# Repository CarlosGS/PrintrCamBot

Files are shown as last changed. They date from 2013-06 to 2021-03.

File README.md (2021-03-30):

PrintrCamBot v0.1  
============

An open-source 3D-printable **Dropcam carrier for Printrbot's challenge.**  

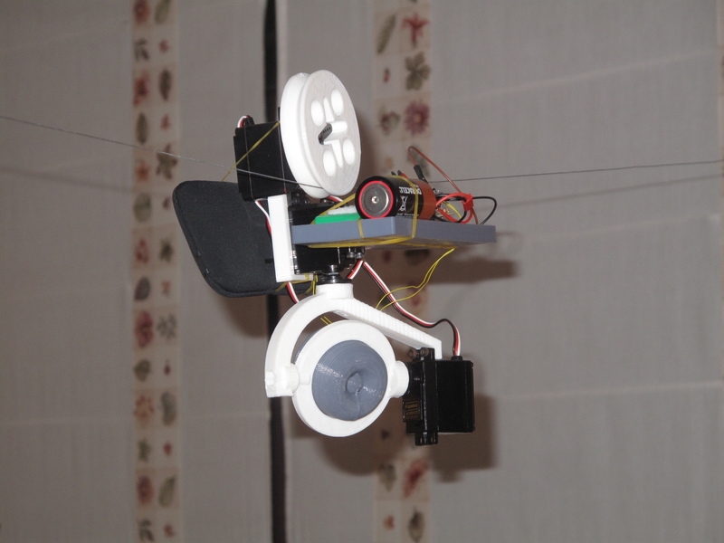
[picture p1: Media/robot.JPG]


Summary  
--
My name is Carlos García Saura, and I'm a student from Spain. **I am a true fan of Printrbot, and I also love making robots, so you can imagine my face when I saw this:**  

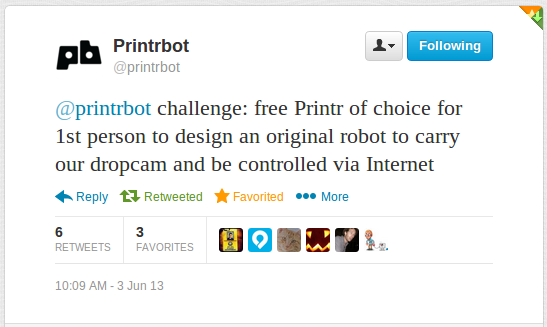
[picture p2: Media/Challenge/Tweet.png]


I would love to get my hands on a Printrbot Simple, maybe this could be my chance! :P  

Basically, my approach is based on two different ideas:  

- ~~Since the Dropcam has two-way audio incorporated, why not use that to send DTMF audio tones to control the robot? (more details below)~~  
- **A "flying fox" robot could easily travel around Printrbot's warehouse without disturbing their workspace** You would just need to place a tense wire from one side to the other of the place to monitor.  

**I would love to see this robot moving around Printrbot's HQ**  

(6 June 2013) DTMF discarded, new approach!  
--
Brook has told me that Dropcam's speaker can only be controlled by the owner (D'Oh!).  
So here is the new setup idea:  
- The robot is kept really simple: **Replace the DTMF board with a cheap Bluetooth module.** I can make a compact electronics board for this.
- **In any computer, plug a USB bluetooth dongle. A simple Python script will then communicate with both the robot AND Printrbot's server.** At first I thought of using a Raspberry Pi, but this is cheaper and will work as well! :)
- **At Printrbot's server, install a simple script. Its mission is to present users with a simple controller interface, and queue them for "time slots".** This way you can easily send commands to the robot from the server.

**The cost is still very low:** Arduino board in the robot (~15$) + Cheap Bluetooth Module (~$5) + Bluetooth USB dongle (~$10, free if you already have one!)  
And the robot itself could use *(depending on the design you finally choose)* three or four servos + a Li-Po battery (with 5V regulator).  

**Links of interest:**  
- Python and Bluetooth <http://homepages.ius.edu/RWISMAN/C490/html/PythonandBluetooth.htm>  
- Bluetooth communication between Arduino and PyBluez <http://stackoverflow.com/questions/15486570/bluetooth-communication-between-arduino-and-pybluez>  
- Python interaction with website <http://ubuntuforums.org/showthread.php?t=624944>  
- Web interaction using Python <http://www.hackthissite.org/articles/read/1053/>  
- How to use Python in the web <http://docs.python.org/3.1/howto/webservers.html>  
- Python application communicating with a web server <http://stackoverflow.com/questions/7975031/python-application-communicating-with-a-web-server-ideas>  
- Internet Controlled Robot with User Queue System <http://forums.parallax.com/showthread.php/139284-Live-Internet-Controlled-Robot-with-User-Queue-System>  

(11 June 2013) Update: Pause!  
--
Sadly, it won't be possible for me to develop the web interface (at least soon) :S  
I'm more of a hardware guy, so my first Web UI attempts have been a bit of a disaster! Not to mention that the code needs to be robust against hacker attacks: I have very little experience dealing with those kind of issues.  

Also, there is too many stuff for me to keep up with before I leave to the US next week (will be in California for two months).  
It would be great to have a Printrbot Simple that I can leave at my cousins place, so please let us know if we could have some discount! :)  

Anyway, it has been a honor to collaborate with this design and am willing to help with electronics/hardware :) Can't wait to control your Dropcam!  
Thank you Printrbot for promoting Open Source, and good luck to the rest of participants!  

Video (5 June 2013)  
--
For this test, I fixed my Android Phone to the back of the robot, and added a heavy battery on the other side as a weight to stabilize the robot.
The additional weight plus the thin wire that I have used make the robot quite unstable (it is the first test, what did you expect? ;)  

I have then stabilished a call via Skype (for the DropCam, this will be done pressing the "Talk" button, and then using a DTMF generator on any smartphone, holding it next to the mic).  

The dial-up tones coming out from the speaker of the smartphone -I insist, this could be directly the Dropcam- are then interpreted by the DTMF decoder + Arduino Nano to move the servos.

**VIDEO: <http://www.youtube.com/watch?v=sOZ26wGzT1U>**

**Unfortunately, I don't have a Dropcam to do proper tests. But as it is shown in the video, this robot can control a Dropcam via internet using its speaker.**

Details  
--
I have printed all the parts using my Printrbot Jr, which I bought last summer. **This printer feels very lonely and would love to have a Printrbot Simple as a friend :)**  
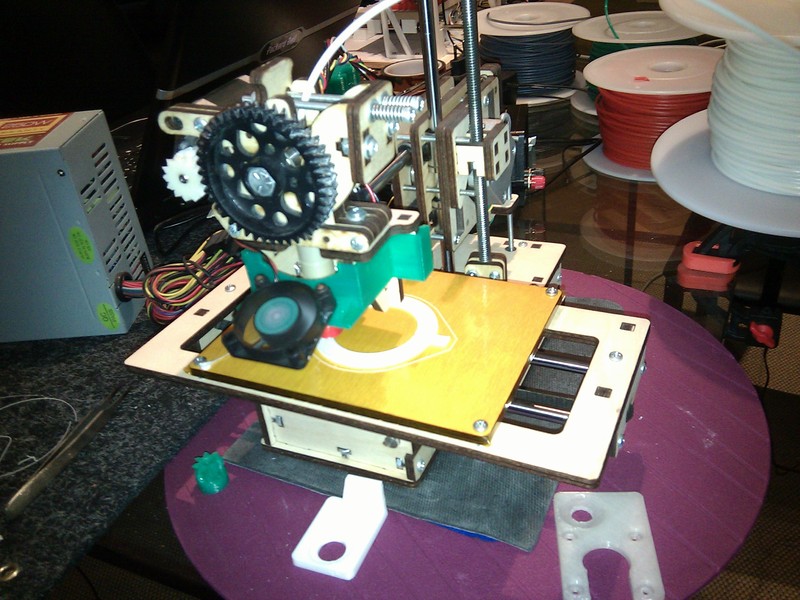
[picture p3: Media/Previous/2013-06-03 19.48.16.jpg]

The parts have been designed with OpenScad and are parametric, don't forget to add the real diameter of the Dropcam before printing!  

For the electronics, I have developed a DTMF decoder board and manufactured it in **Cyclone PCB Factory** (<https://github.com/carlosgs/Cyclone-PCB-Factory>). **It has been the first circuit manufactured with this new open-hardware machine! :P**  
If Printrbot likes my idea, I will send them the electronics assembled so they don't need to worry about it.

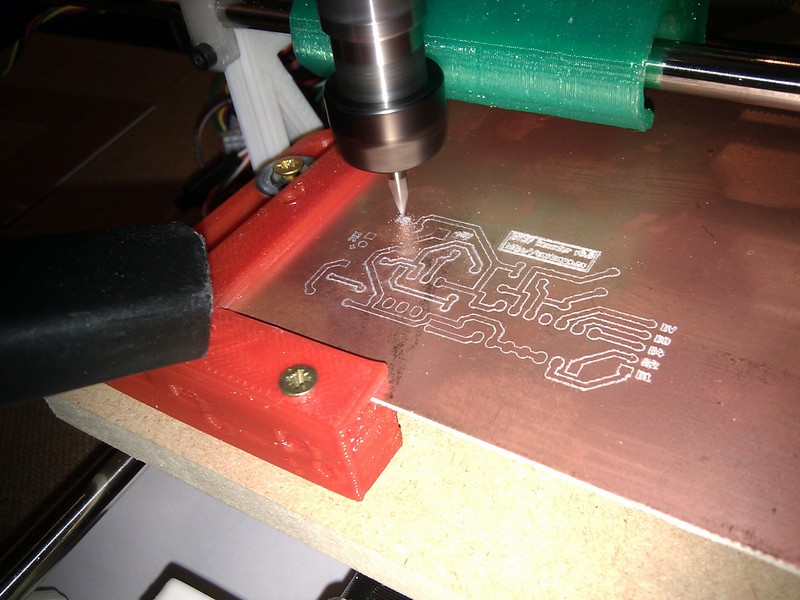
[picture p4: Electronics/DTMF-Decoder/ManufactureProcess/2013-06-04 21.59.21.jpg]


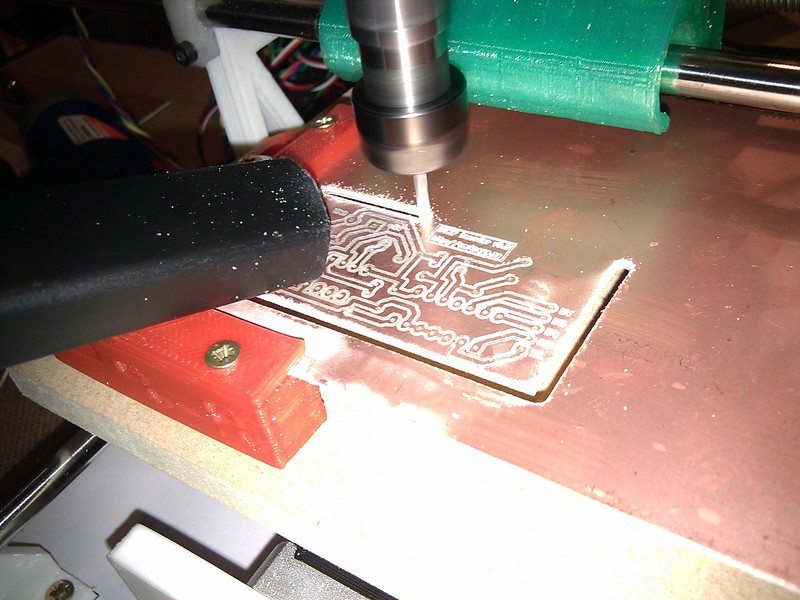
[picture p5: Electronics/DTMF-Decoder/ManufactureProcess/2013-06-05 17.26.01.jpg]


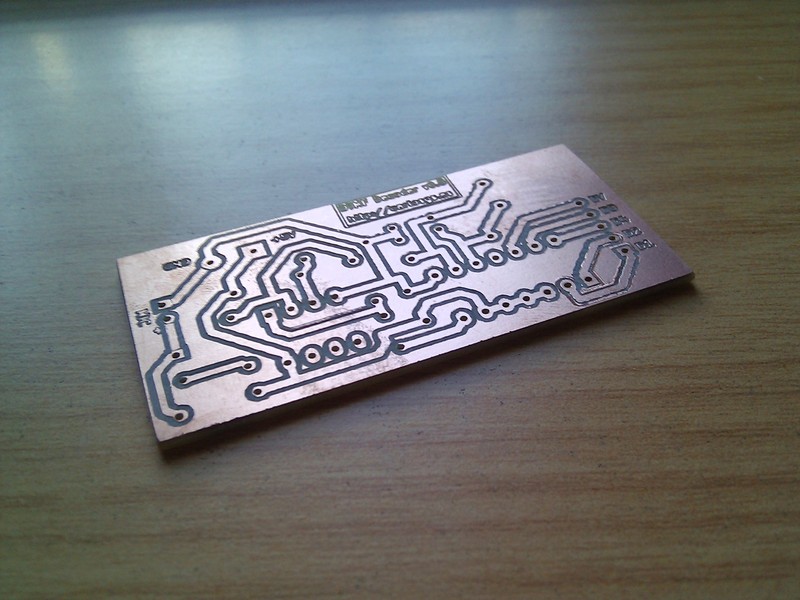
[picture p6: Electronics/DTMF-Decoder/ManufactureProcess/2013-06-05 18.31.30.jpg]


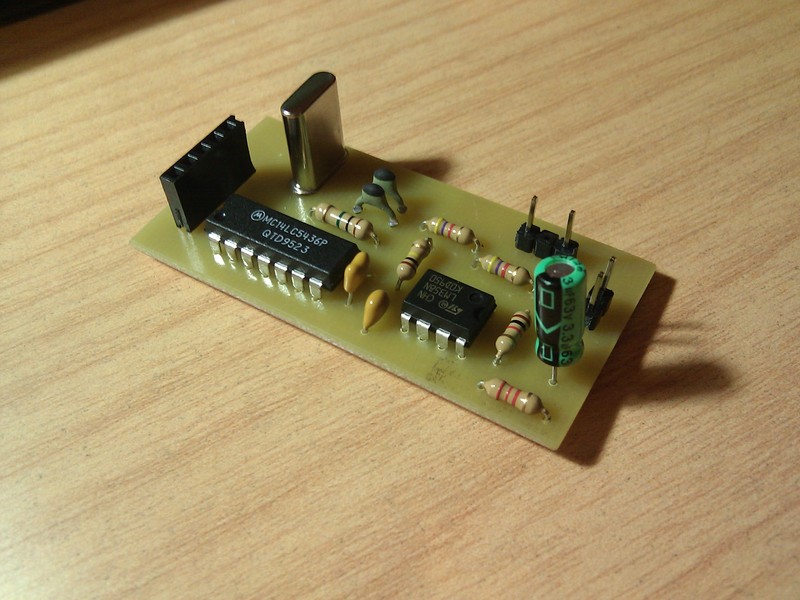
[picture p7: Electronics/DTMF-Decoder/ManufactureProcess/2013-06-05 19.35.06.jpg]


Regarding Dropcam's power supply
--
The tray of the robot has been designed to carry a medium-sized Li-Po battery, and also a 5V regulator. This would supply the 2A required by the Dropcam, and the few milliamps required by the rest of the robot.

To-Do list
--
- Add counter-balance weight for the main frame
- Add second "travel wheel" to improve stability
- Wait for Printrbot's feedback! :)

Credit  
--
This project has been possible thanks to the following work:
- MiniSkyBot Wheel by **Obijuan** (<https://github.com/Obijuan/Miniskybot>)  
- Dropcam Tripod Mount by **Reuben** (<http://www.thingiverse.com/thing:39078>)  
- Yazzo Servo Side Shelf Mount by **WilliamAAdams** (<http://www.thingiverse.com/thing:6668>)  
- Skype-controlled robot using smartphone and DTMF tones by **Janisalnis** (<http://www.instructables.com/id/Skype-controlled-robot-using-smartphone-and-DTMF-t/>)  
- Electret mic interfacing by **Chrille2k** and **BillHo** (<http://forum.arduino.cc/index.php/topic,19052.0.html>)  
- Kicad Arduino nano (YJ_arduino: component and module) by **Yann Jautard**  

License  
--
License: **Attribution - Share Alike - Creative Commons (<http://creativecommons.org/licenses/by-sa/3.0/>)**  

Author:  
--
- Carlosgs

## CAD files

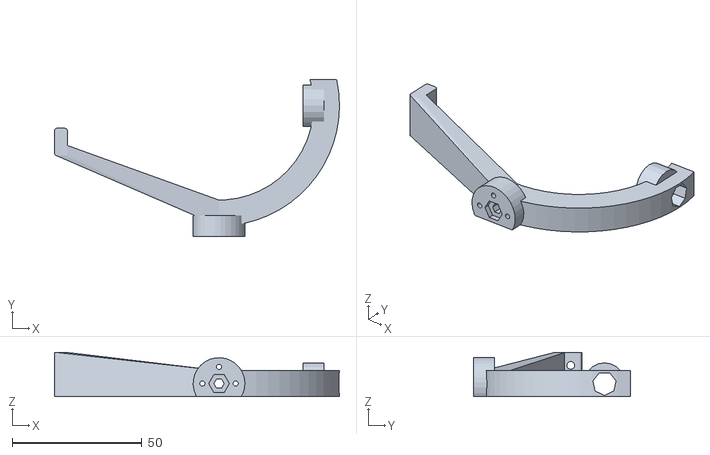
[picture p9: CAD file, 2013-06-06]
Hardware/STL/MainFrame.stl
110.0 x 60.5 x 17.0

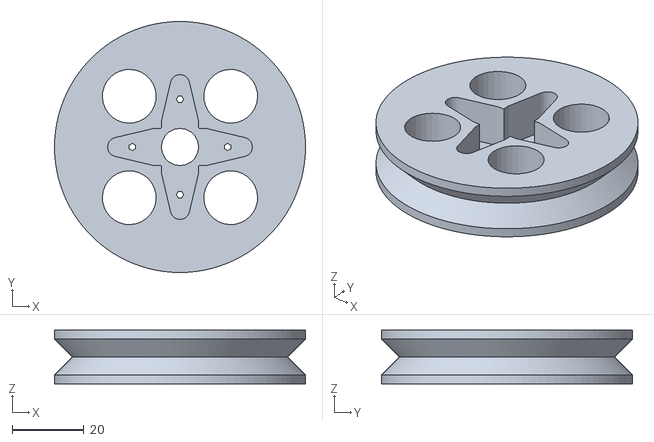
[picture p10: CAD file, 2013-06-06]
Hardware/STL/Servo-wheel.stl
70.0 x 70.0 x 15.0

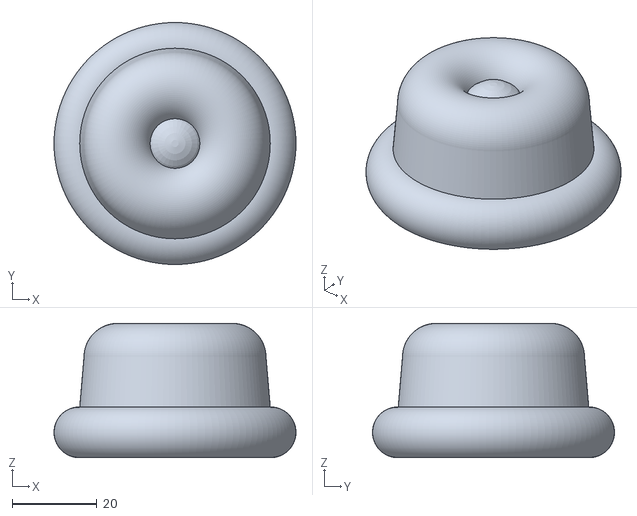
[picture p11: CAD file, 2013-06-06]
Hardware/STL/DummyDropcamModel.stl
57.1 x 57.1 x 31.8

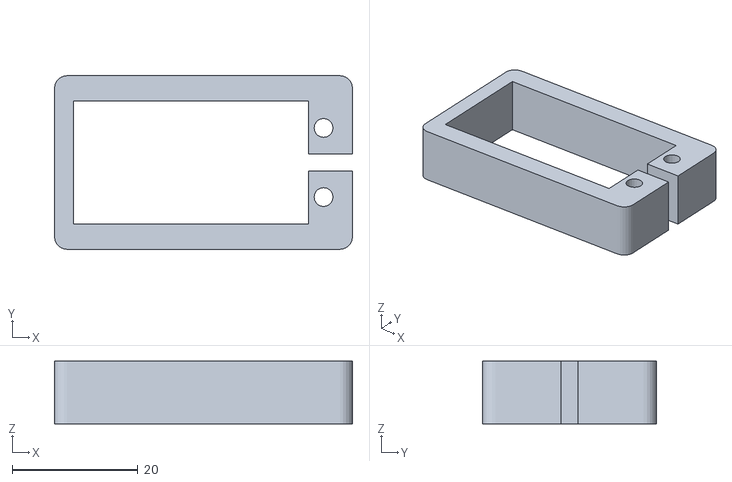
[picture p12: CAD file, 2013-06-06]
Hardware/STL/travel_servo_holder.stl
47.4 x 27.6 x 10.0

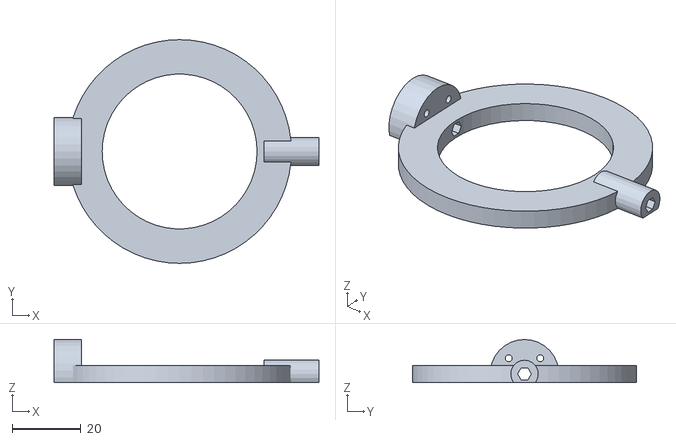
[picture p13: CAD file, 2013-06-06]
Hardware/STL/DropcamHolder.stl
77.0 x 65.0 x 12.5

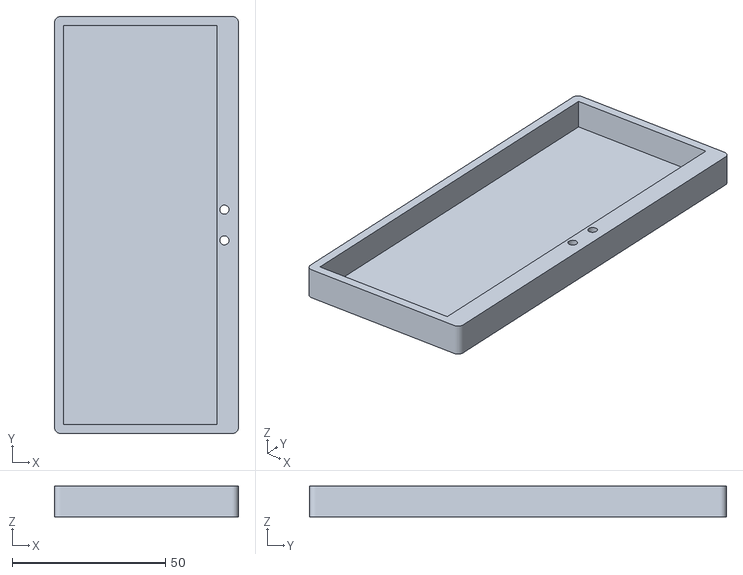
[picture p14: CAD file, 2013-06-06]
Hardware/STL/tray.stl
60.0 x 136.0 x 10.0

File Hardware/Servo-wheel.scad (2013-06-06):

//-------------------------------------------------------------
// Servo wheel for the PrintrCamBot by Carlosgs (http://carlosgs.es)
// Derived from:
//-- Servo wheel
//-- (c) Juan Gonzalez (obijuan) juan@iearobotics.com
//-- March-2012
//-------------------------------------------------------------
//-- Wheel for mobile robots, drived by Futaba 3003 servos
//-------------------------------------------------------------

//-------------------------------------------------
//-- Wheels parameters. 
//-- See the doc/Servo-wheels-doc.pdf
//------------------------------------------------
wheel_or_idiam = 50;                   //-- O-ring inner diameter
wheel_or_diam = 10;                     //-- O-ring section diameter
wheel_height = 2*wheel_or_diam-5;     //-- Wheel height: change the 0 for 
                                      //-- other value (0 equals minimun height)
                                      
//-- Wheel diameter is calculated from the o_ring                                      
wheels_diam = wheel_or_idiam + 2*wheel_or_diam;
wheel_gap = 1;  //-- For the final view. space between servo and wheel

//-- Parameters common to all horns
horn_drill_diam = 2;
horn_height = 6;        //-- Total height: shaft + plate
horn_plate_height = 3;  //-- plate height

//-- Futaba 3003 servo rounded horn parameters
rh_diam1 = 8.5;  //-- Rounded horn small diameter
rh_diam2 = 21.5; //-- Rounded horn big diameter
rounded_horn_drill_distance = 7.3;

//-- Futaba 3003 4-arm horn parameters
a4h_end_diam = 5.4;
a4h_center_diam = 10.4;
a4h_arm_length = 15;
a4h_drill_distance = 13.3;


//-- Futaba 3003 6-arm horn parameters
a6h_end_diam = 5;
a6h_center_diam = 10;
a6h_arm_length=10;
a6h_arm_base_diam=7.5;
a6h_drill_distance = 10.9;


//-------------------------------------------------------
//--- Parameters:
//-- or_idiam: O-ring inner diameter
//-- or_diam: O-ring section diameter
//-- h: Height of the wheel
//--
//--  Module for generating a raw wheel, with no drills
//--  and no servo horn
//-------------------------------------------------------
module raw_wheel(or_idiam=50, or_diam=3, h=6)
{
   //-- Wheel parameters
   r = wheels_diam / 2;   //-- Radius

  //-- Temporal points
  l = or_diam*sqrt(2)/2;

  difference() {
    //-- Body of the wheel
    cylinder (r=r, h=h, $fn=100,center=true);

    //--  wheel's inner section
    rotate_extrude($fn=100)
      translate([r-or_diam/2,0,0])
      polygon( [ [0,0],[l,l],[l,-l] ] , [ [0,1,2] ]);
  }
}

//--------------------------------------------------------------
//-- Generic module for the horn's drills
//-- Parameters:
//--  d = drill's radial distance (from the horn's center)
//--  n = number of drills
//--  h = wheel height
//--------------------------------------------------------------
module horn_drills(d,n,h)
{
  union() {
    for ( i = [0 : n-1] ) {
        rotate([0,0,i*360/n])
        translate([0,d,0])
        cylinder(r=horn_drill_diam/2, h=h+10,center=true, $fn=6);  
      }
  }
}

//-----------------------------------------
//-- Futaba 3003 horn4 arm
//-- This module is just one arm
//-----------------------------------------
module horn4_arm(h=5)
{
  translate([0,a4h_arm_length-a4h_end_diam/2,0])
  //-- The arm consist of the perimeter of a cylinder and a cube
  hull() {
    cylinder(r=a4h_end_diam/2, h=h, center=true, $fn=20);
    translate([0,1-a4h_arm_length+a4h_end_diam/2,0])
      cube([a4h_center_diam,2,h],center=true);
  }
}

//-----------------------------------------
//-- Futaba 3003 horn6 arm
//-- This module is just one arm
//-----------------------------------------
module horn6_arm(h=5)
{
  translate([0,a6h_arm_length-a6h_end_diam/2,0])
  //-- The arm consist of the perimeter of a cylinder and a cube
  hull() {
    cylinder(r=a6h_end_diam/2, h=h, center=true, $fn=20);
    translate([0,-a6h_arm_length+a6h_end_diam/2,0])
    cube([a6h_arm_base_diam,0.1,h],center=true);
  }
}


//-------------------------------------------
//-- Futaba 3003 4-arm horn
//-------------------------------------------
module horn4(h=5)
{
  union() {
    //-- Center part (is a square)
    cube([a4h_center_diam+0.2,a4h_center_diam+0.2,h],center=true);

    //-- Place the 4 arms in every side of the cube
    for ( i = [0 : 3] ) {
      rotate( [0,0,i*90])
      translate([0, a4h_center_diam/2, 0])
      horn4_arm(h);
    }
  }

}

//-------------------------------------------
//-- Futaba 3003 6-arm horn
//-------------------------------------------
module horn6(h=5)
{
  union() {
    //-- The center part is a cylinder
    cylinder(r=15/2,h=h,center=true);

    //-- Place the 6 arms rotated 60 degrees
    for ( i = [0 : 5] ) {
      rotate( [0,0,i*60])
      translate([0, 15/2*cos(30), 0])
      horn6_arm(h);
    }
  }
}


//-------------------------------------------------------
//--  A Wheel for the futaba 3003 rounded horns
//--------------------------------------------------------
module Servo_wheel_rounded_horn()
{
  difference() {
      raw_wheel(or_idiam=wheel_or_idiam, or_diam=wheel_or_diam, h=wheel_height);

      //-- Inner drill
      cylinder(center=true, h=2*wheel_height + 10, r=rh_diam1/2+0.2,$fn=100);

      //-- Carved circle for the Futaba rounded horn
      translate([0,0,-wheel_height/2+horn_height-horn_plate_height]) 
       cylinder(r=rh_diam2/2+0.25, h=2*wheel_height+10,$fn=30);

      //-- small drills for the rounded horn
      horn_drills(d=rounded_horn_drill_distance, n=4, h=wheel_height);
  }

}


nholes = 4;
hole_distance_from_center = wheel_or_idiam/2-wheel_or_diam/2;
holes_diam = 15;

//-------------------------------------------------------
//--  A Wheel for the futaba 3003 4-arm horns
//--------------------------------------------------------
module Servo_wheel_4_arm_horn()
{
  difference() {
      raw_wheel(or_idiam=wheel_or_idiam, or_diam=wheel_or_diam, h=wheel_height);

      //-- Inner drill
      cylinder(center=true, h=2*wheel_height + 10, r=a4h_center_diam/2,$fn=20);

      //-- substract the 4-arm servo horn
      translate([0,0,horn_height-horn_plate_height])
        horn4(h=wheel_height);

      //-- Horn drills
      horn_drills(d=a4h_drill_distance, n=4, h=wheel_height);

  //holes to save plastic
  for(i=[0:nholes-1])
    rotate( [0, 0, i*360/(nholes)+45], $fn=20 )
      translate( [hole_distance_from_center, 0] )
        cylinder( r=holes_diam/2, h=100, center=true, $fn=30 );
  }
}

//-------------------------------------------------------
//--  A Wheel for the futaba 3003 6-arm horns
//--------------------------------------------------------
module Servo_wheel_6_arm_horn()
{
  difference() {
      raw_wheel(or_idiam=wheel_or_idiam, or_diam=wheel_or_diam, h=wheel_height);

       //-- Inner drill
      cylinder(center=true, h=2*wheel_height + 10, r=a6h_center_diam/2,$fn=20);

      //-- substract the 6-arm horn
      translate([0,0,horn_height-horn_plate_height])
      horn6(h=wheel_height);

      //-- Horn drills
      horn_drills(d=a6h_drill_distance, n=6, h=wheel_height);
  }
}


//-- Test!

//Servo_wheel_rounded_horn();
//translate([wheel_or_idiam+10,0,0]) 
Servo_wheel_4_arm_horn();

//translate([-wheel_or_idiam-10,0,0]) Servo_wheel_6_arm_horn();


/*-- Calculating the top view (for the documentation) 
projection(cut=false)
Servo_wheel_4_arm_horn();
*/


/*-- Horn6. Used in the freecad drawing
translate([0, 0, 4/2 + 2/2],$fn=50)
cylinder(r=8.5/2, h=4, center=true);
horn4(h=2);
*/

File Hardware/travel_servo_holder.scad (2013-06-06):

// Travel Servo Holder for the PrintrCamBot by Carlosgs (http://carlosgs.es)

use <obiscad/bcube.scad>

servo_h = 37+0.4;
servo_w = 19.22+0.4;

holder_w = 10;

holder_thickness = 7;

base_truncation = holder_thickness-3;
side_truncation = holder_thickness-4;

screwOffset = 2.4;

screwDistFromOrig = servo_h/2+screwOffset;
screwSupport_h = 5;

screwDist = 10+1;// We add a millimiter to increase tension, and thus have a better grip on the servo

screwDiam = 3;

module screws() {
	translate([0,screwDist/2,0]) {
		cylinder(r=screwDiam/2,h=100,center=true,$fn=20);
	}
	translate([0,-screwDist/2,0]) {
		cylinder(r=screwDiam/2,h=100,center=true,$fn=20);
	}
}

difference() {
	translate([base_truncation/2,0,0])
		bcube([servo_h+holder_thickness*2-base_truncation,servo_w+holder_thickness*2-side_truncation*2,holder_w],cr=2,cres=5);
	cube([servo_h,servo_w,holder_w*2],center=true);
	translate([screwDistFromOrig,0,0]) screws();
	translate([screwDistFromOrig,0,0]) cube([servo_h,screwDist/4,holder_w*2],center=true);
}

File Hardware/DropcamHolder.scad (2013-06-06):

// DropCamHolder for the PrintrCamBot by Carlosgs (http://carlosgs.es)

dropcam_diameter = 45; // [mm] Adjust to real value before printing!
dropcam_plate_thickness = 5; // [mm]


dropcam_plate_extraRadius = 10;

dh_ringRadius = dropcam_diameter/2+dropcam_plate_extraRadius;

idleHolderDiam = 8;
idleHolderLen = 8;

servoHolderDiam = 20;
servoHolderLen = 8/2;

axisHoleDiam = 4;

module holderRing() {
	difference() {
		cylinder(r=dh_ringRadius,h=dropcam_plate_thickness,center=true,$fn=60);
		cylinder(r=dropcam_diameter/2,h=dropcam_plate_thickness*2,center=true,$fn=50);
	}
}



nholes = 4;
hole_distance_from_center = 6.45;
holes_diam = 2;

module servoHolder(holeAngle=90) {
	difference() {
		cylinder(r=servoHolderDiam/2,h=servoHolderLen*2,center=true,$fn=30);
		//screws
		for(i=[0:nholes-1])
			rotate( [0, 0, i*360/(nholes)+45], $fn=20 )
				translate( [hole_distance_from_center, 0] )
					cylinder( r=holes_diam/2, h=100, center=true, $fn=30 );
		// Hole for the middle screw
		translate([0,0,2]) rotate([0,0,holeAngle]) cylinder(r=axisHoleDiam,h=10,$fn=6);
	}
}




module idleHolder() {
	cylinder(r=idleHolderDiam/2,h=idleHolderLen*2,center=true,$fn=20);
}

module dropCamHolder() {
	difference() {
		union() {
			holderRing();
			translate([dh_ringRadius,0,0]) rotate([0,90,0])
				idleHolder();
			translate([-dh_ringRadius,0,0]) rotate([0,-90,0])
				servoHolder();
		}
		translate([0,0,-dropcam_plate_thickness/2-100/2])
			cube([100,100,100],center=true);
		// Axis hole
		rotate([0,90,0]) rotate([0,0,90]) cylinder(r=axisHoleDiam/2,h=200,center=true,$fn=6);
	}
}

//dropCamHolder();

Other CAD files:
Hardware/DummyDropcamModel.scad
Hardware/MainFrame.scad
Hardware/obiscad/attach.scad
Hardware/obiscad/bcube.scad
Hardware/obiscad/bevel.scad
Hardware/obiscad/utils.scad
Hardware/obiscad/vector.scad
Hardware/tray.scad

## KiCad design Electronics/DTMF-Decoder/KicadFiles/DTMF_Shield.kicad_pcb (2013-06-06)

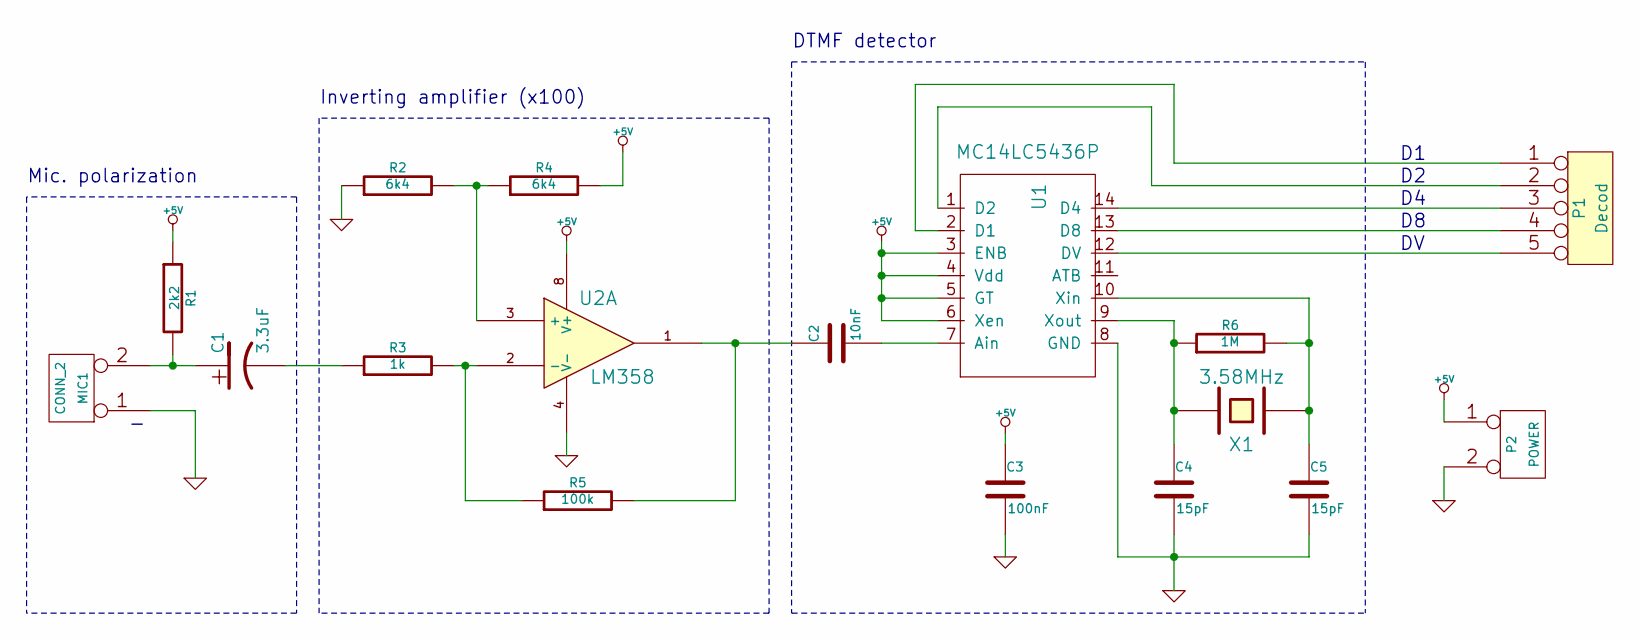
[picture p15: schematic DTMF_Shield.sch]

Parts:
C1: 3.3uF
C2: 10nF
C3: 100nF
C4, C5: 15pF
MIC1: CONN_2
P1: Decod
P2: POWER
R1: 2k2
R2, R4: 6k4
R3: 1k
R5: 100k
R6: 1M
U1: MC14LC5436P
U2: LM358
X1: 3.58MHz

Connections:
+5V: C3.1, P2.1, R1.1, R4.2, U1.3 (ENB), U1.4 (Vdd), U1.5 (GT), U1.6 (Xen), U2.8 (V+)
GND: C3.2, C4.2, C5.2, MIC1.1, P2.2 (PM), R2.1, U1.8 (GND), U2.4 (V-)
unnamed: C5.1, R6.2, U1.10 (Xin), X1.1
unnamed: C2.1, R5.2, U2.1
unnamed: R3.2, R5.1, U2.2 (-)
unnamed: C4.1, R6.1, U1.9 (Xout), X1.2
unnamed: C2.2, U1.7 (Ain)
unnamed: P1.4, U1.13 (D8)
unnamed: P1.1, U1.2 (D1)
unnamed: P1.2, U1.1 (D2)
unnamed: P1.3, U1.14 (D4)
unnamed: P1.5, U1.12 (DV)
unnamed: R2.2, R4.1, U2.3 (+)
unnamed: C1.1, MIC1.2 (PM), R1.2
unnamed: C1.2, R3.1

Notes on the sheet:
Inverting amplifier (x100)
Mic. polarization
DTMF detector

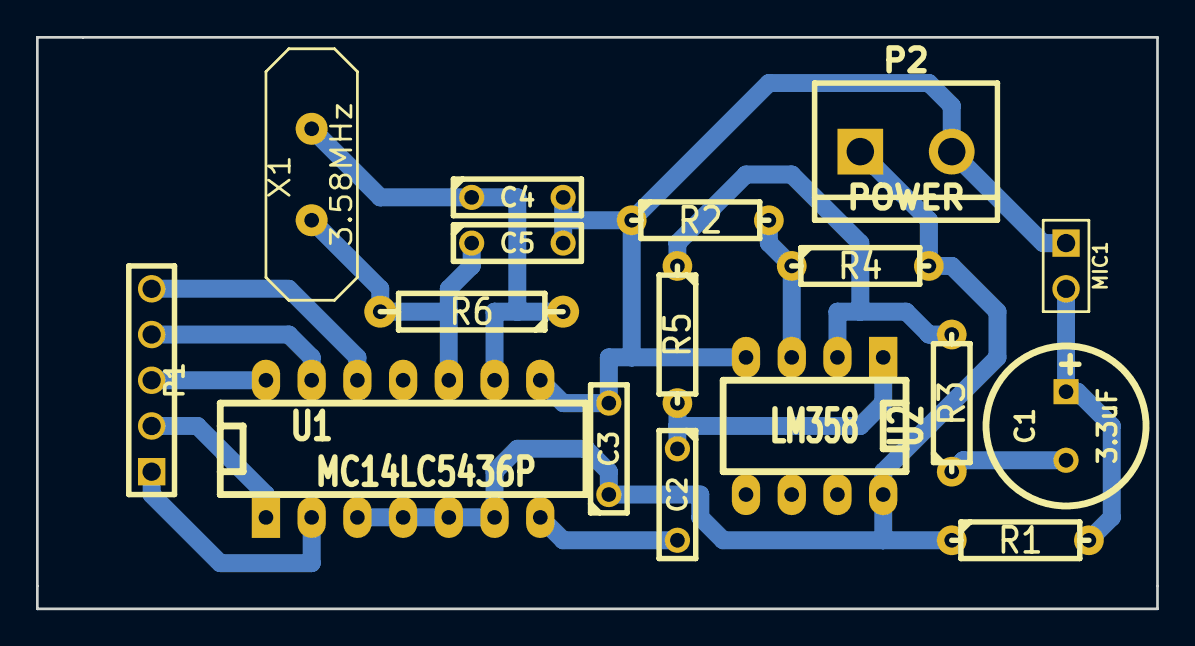
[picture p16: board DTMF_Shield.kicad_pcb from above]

Board: 2 copper layers, 62.2 x 31.7 mm, 17 parts (0 on the bottom side), 15 nets.

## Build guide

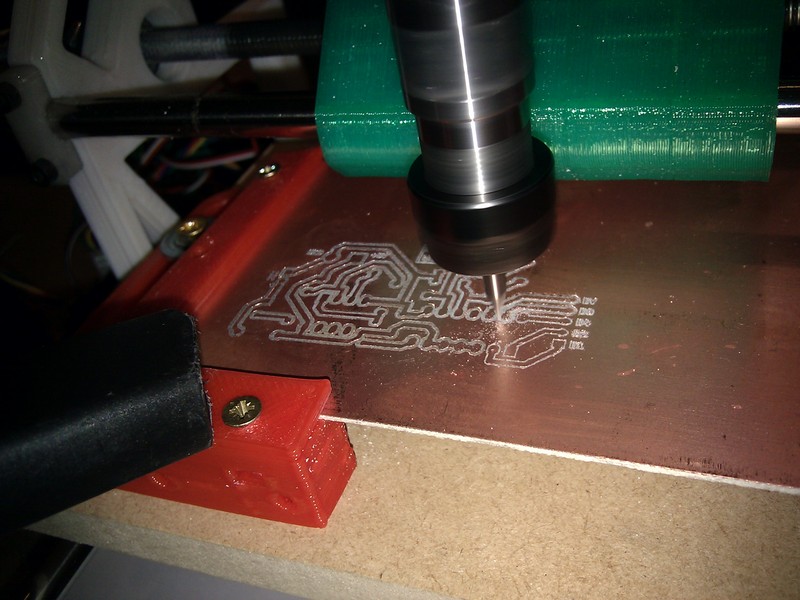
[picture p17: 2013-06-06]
Electronics/DTMF-Decoder/ManufactureProcess/2013-06-05 16.36.12.jpg

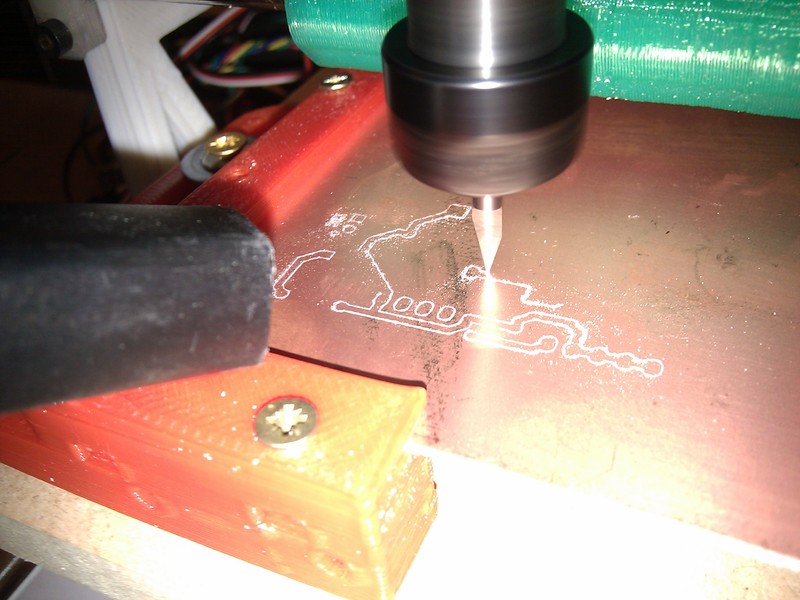
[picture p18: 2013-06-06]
Electronics/DTMF-Decoder/ManufactureProcess/2013-06-04 21.43.21.jpg

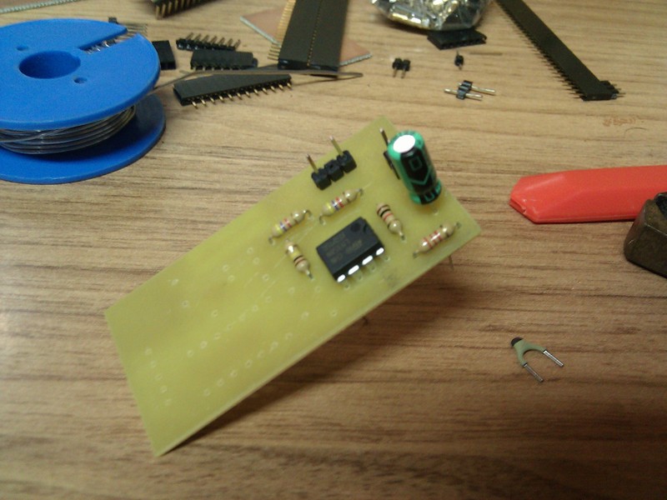
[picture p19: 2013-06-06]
Electronics/DTMF-Decoder/ManufactureProcess/2013-06-05 19.06.58.jpg

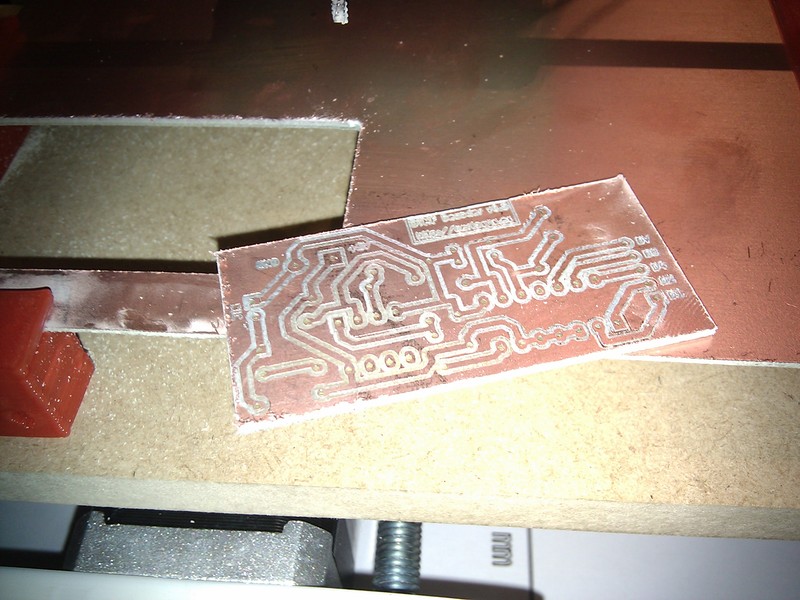
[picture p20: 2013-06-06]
Electronics/DTMF-Decoder/ManufactureProcess/2013-06-05 17.27.54.jpg

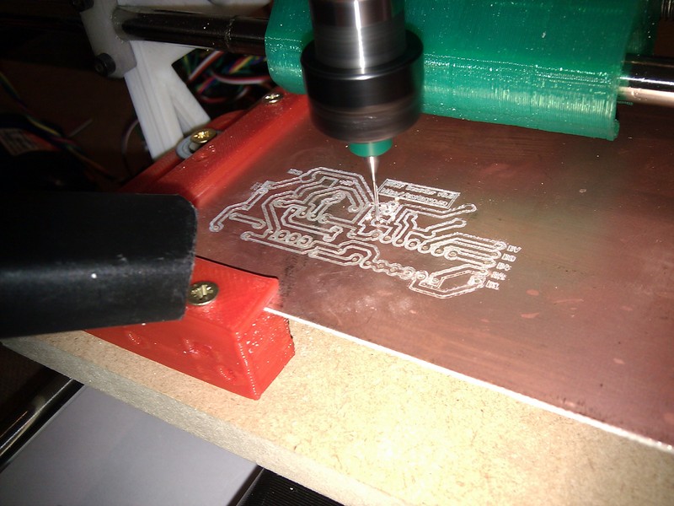
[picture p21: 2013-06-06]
Electronics/DTMF-Decoder/ManufactureProcess/2013-06-05 16.58.07.jpg

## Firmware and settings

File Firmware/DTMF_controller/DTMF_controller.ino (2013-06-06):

// DTMF controller by Carlosgs (http://carlosgs.es)
// License: CC-BY-SA (http://creativecommons.org/licenses/by-sa/3.0/)

#include <Servo.h>

#define LED_PIN 13

#define D1_PIN 8
#define D2_PIN 9
#define D4_PIN 10
#define D8_PIN 11
#define DataValid_PIN 12

#define TRAVEL_SERVO_PIN 3
#define PAN_SERVO_PIN 2
#define TILT_SERVO_PIN 4

Servo travelServo;
Servo panServo;
Servo tiltServo;

//travelPos = 90;
int panPos = 90;
int tiltPos = 90;

int travelSpeed = 30; // 0-90 | MIN-MAX

int inter_reading_delay = 25; // [ms]

void setup() {
  delay(1000);
  pinMode(LED_PIN, OUTPUT);
  travelServo.attach(TRAVEL_SERVO_PIN);
  panServo.attach(PAN_SERVO_PIN);
  tiltServo.attach(TILT_SERVO_PIN);
  //Serial.begin(9600);
}

int read_DTMF_val() {
  int ret = digitalRead(D1_PIN)+2*digitalRead(D2_PIN)+4*digitalRead(D4_PIN)+8*digitalRead(D8_PIN);
  return ret;
}

void loop() {
  //travelServo.write(travelPos);
  panServo.write(panPos);
  tiltServo.write(tiltPos);
  
  if(digitalRead(DataValid_PIN)) { // When a tone is detected
    digitalWrite(LED_PIN, HIGH); // Turn on LED
    int command = read_DTMF_val();
    //Serial.println(command);
    switch(command) {
      
      case 1: // Travel left while pressing
        travelServo.write(90+travelSpeed);
        delay(inter_reading_delay);
        while(digitalRead(DataValid_PIN))
          delay(inter_reading_delay);
        travelServo.write(90);
        break;
      case 3: // Travel right while pressing
        travelServo.write(90-travelSpeed);
        delay(inter_reading_delay);
        while(digitalRead(DataValid_PIN))
          delay(inter_reading_delay);
        travelServo.write(90);
        break;
        
      case 2: // Tilt up
        tiltPos++;
        if(tiltPos > 180) tiltPos = 180;
        break;
      case 8: // Tilt down
        tiltPos--;
        if(tiltPos < 0) tiltPos = 0;
        break;
        
      case 4: // Pan left
        panPos++;
        if(panPos > 180) panPos = 180;
        break;
      case 6: // Pan right
        panPos--;
        if(panPos < 0) panPos = 0;
        break;
        
      case 7: // Travel left slow
        travelServo.write(90+travelSpeed/3);
        break;
      case 9: // Travel right slow
        travelServo.write(90-travelSpeed/3);
        break;
        
      case 5: // Stop travel
        travelServo.write(90);// Stop the traveling motion
        break;
    }
  } else { // If no tone is detected, we stop
    digitalWrite(LED_PIN, LOW);
    //travelServo.write(90);// Stop the traveling motion
  }
  delay(inter_reading_delay);
 }
